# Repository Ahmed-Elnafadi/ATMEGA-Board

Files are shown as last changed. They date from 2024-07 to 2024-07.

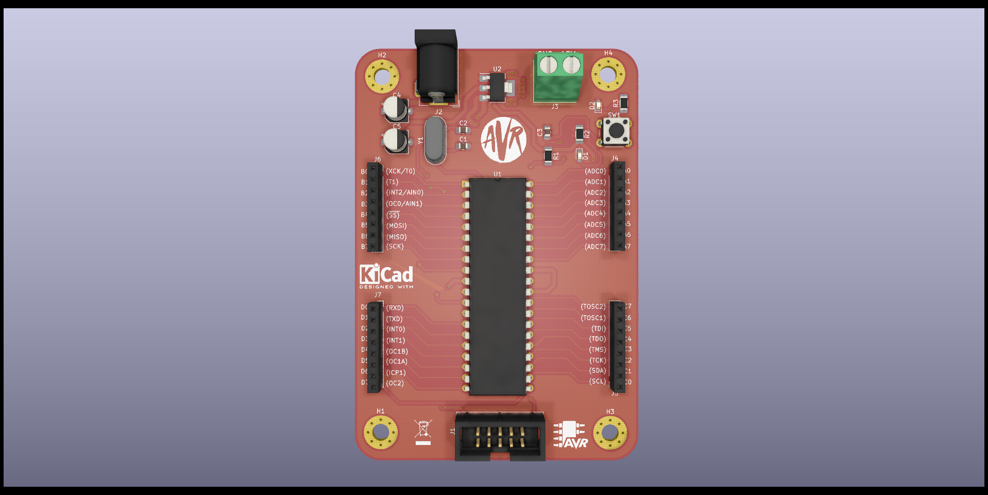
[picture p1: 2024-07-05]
ATMEGA32A_PU_V1_1.png

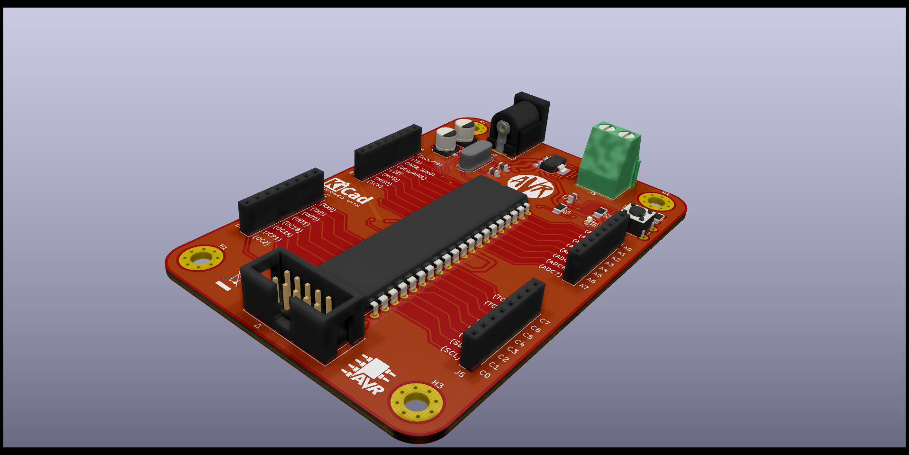
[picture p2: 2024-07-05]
ATMEGA32A_PU_V1_2.png

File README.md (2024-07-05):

# ATMEGA-Board
Developed ATMEGA board for Embedded System Engineers using KiCad Software. 
ATMEGA32A_PU_V1_1

# Real Product after Manufacturing and Assembling:
Real Board

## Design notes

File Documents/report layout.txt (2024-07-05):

Info: Checking netlist symbol footprint "J2:/620A4396:Connector_BarrelJack:BarrelJack_Wuerth_6941xx301002".
Info: Checking netlist symbol footprint "Y1:/620AA581:Crystal:Crystal_HC49-4H_Vertical".
Info: Checking netlist symbol footprint "U2:/620A79AD:Package_TO_SOT_SMD:TO-252-3_TabPin2".
Info: Checking netlist symbol footprint "U1:/62091506:Package_DIP:DIP-40_W15.24mm".
Info: Checking netlist symbol footprint "SW1:/620B355E:Button_Switch_THT:SW_PUSH_6mm".
Info: Checking netlist symbol footprint "R2:/620D214D:Resistor_SMD:R_1206_3216Metric_Pad1.30x1.75mm_HandSolder".
Info: Checking netlist symbol footprint "R1:/620B46D2:Resistor_SMD:R_1206_3216Metric_Pad1.30x1.75mm_HandSolder".
Info: Checking netlist symbol footprint "J7:/620DFF1D:Connector_PinSocket_2.54mm:PinSocket_1x08_P2.54mm_Vertical".
Info: Checking netlist symbol footprint "J6:/620DE13E:Connector_PinSocket_2.54mm:PinSocket_1x08_P2.54mm_Vertical".
Info: Checking netlist symbol footprint "J5:/620E2409:Connector_PinSocket_2.54mm:PinSocket_1x08_P2.54mm_Vertical".
Info: Checking netlist symbol footprint "J4:/620E0EA3:Connector_PinSocket_2.54mm:PinSocket_1x08_P2.54mm_Vertical".
Info: Checking netlist symbol footprint "J3:/620A65EF:TerminalBlock_Phoenix:TerminalBlock_Phoenix_MKDS-1,5-2_1x02_P5.00mm_Horizontal".
Info: Checking netlist symbol footprint "C1:/620AC6F6:Capacitor_SMD:C_0805_2012Metric_Pad1.18x1.45mm_HandSolder".
Info: Checking netlist symbol footprint "J1:/620DBA1B:Connector_IDC:IDC-Header_2x05_P2.54mm_Vertical".
Info: Checking netlist symbol footprint "H4:/620AEA69:MountingHole:MountingHole_4mm_Pad_Via".
Info: Checking netlist symbol footprint "H3:/620B0146:MountingHole:MountingHole_4mm_Pad_Via".
Info: Checking netlist symbol footprint "H2:/620AF71E:MountingHole:MountingHole_4mm_Pad_Via".
Info: Checking netlist symbol footprint "H1:/620AFCA4:MountingHole:MountingHole_4mm_Pad_Via".
Info: Checking netlist symbol footprint "D1:/620D2A8D:LED_SMD:LED_0603_1608Metric_Pad1.05x0.95mm_HandSolder".
Info: Checking netlist symbol footprint "C5:/620C8B24:Capacitor_SMD:CP_Elec_5x5.3".
Info: Checking netlist symbol footprint "C4:/620C6410:Capacitor_SMD:CP_Elec_5x5.3".
Info: Checking netlist symbol footprint "C3:/620B60D1:Capacitor_SMD:C_0805_2012Metric_Pad1.18x1.45mm_HandSolder".
Info: Checking netlist symbol footprint "C2:/620ACF85:Capacitor_SMD:C_0805_2012Metric_Pad1.18x1.45mm_HandSolder".

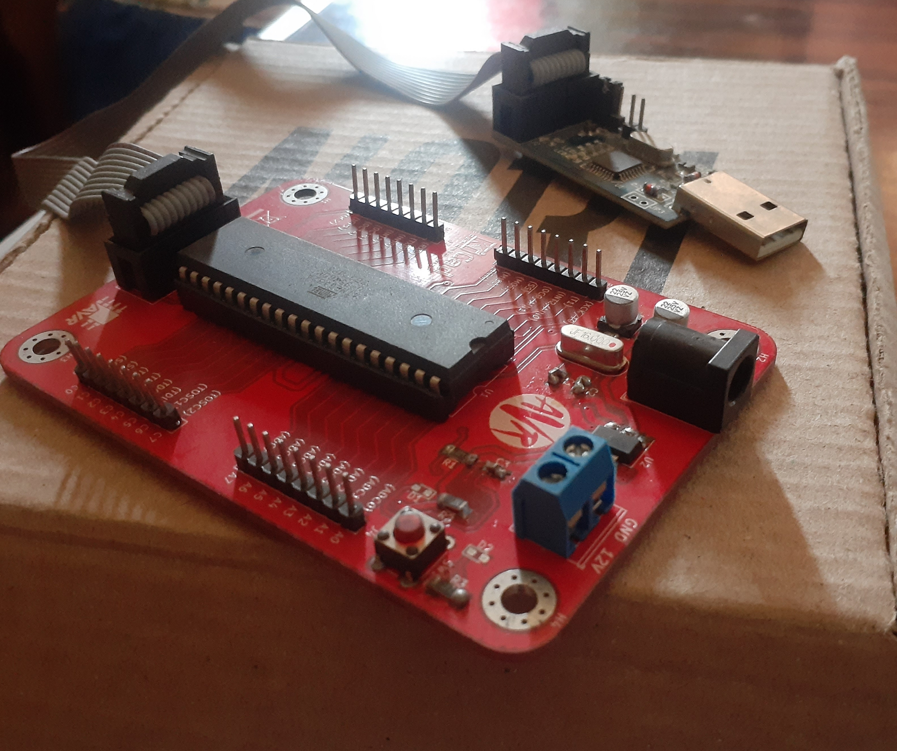
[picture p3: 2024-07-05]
Real Board.jpg

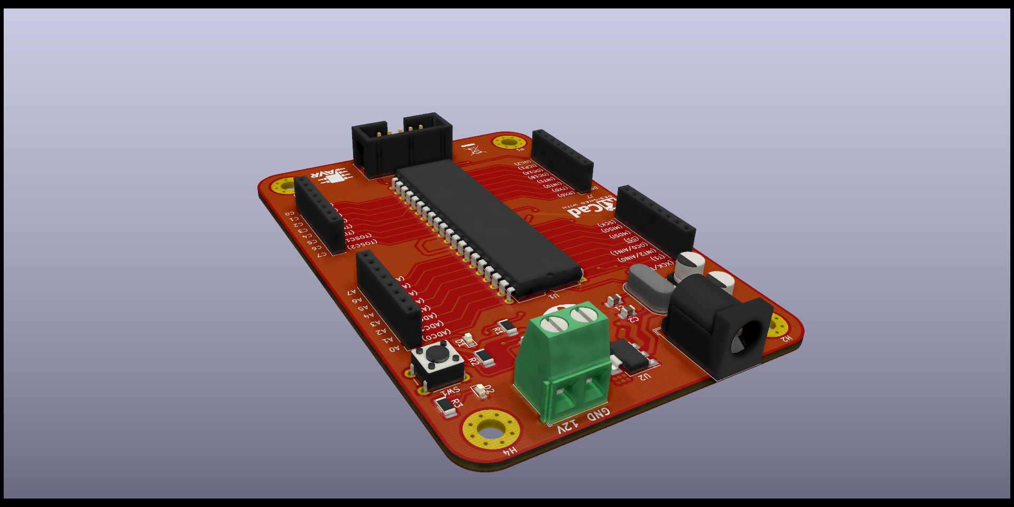
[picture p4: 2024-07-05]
ATMEGA32A_PU_V1_3.png

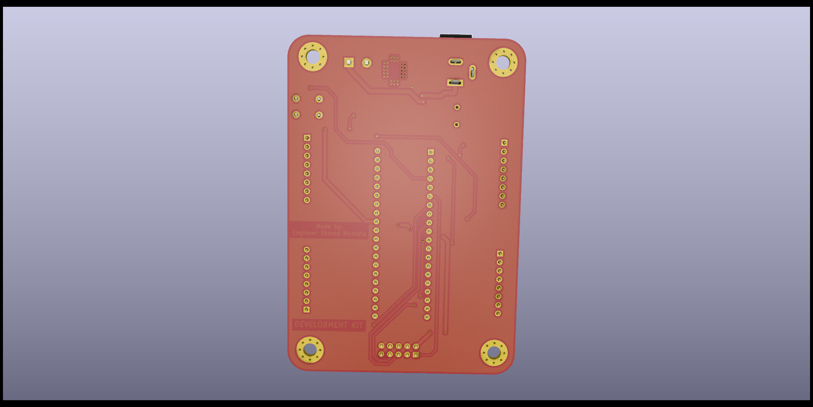
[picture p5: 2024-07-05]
ATMEGA32A_PU_V1_6.png

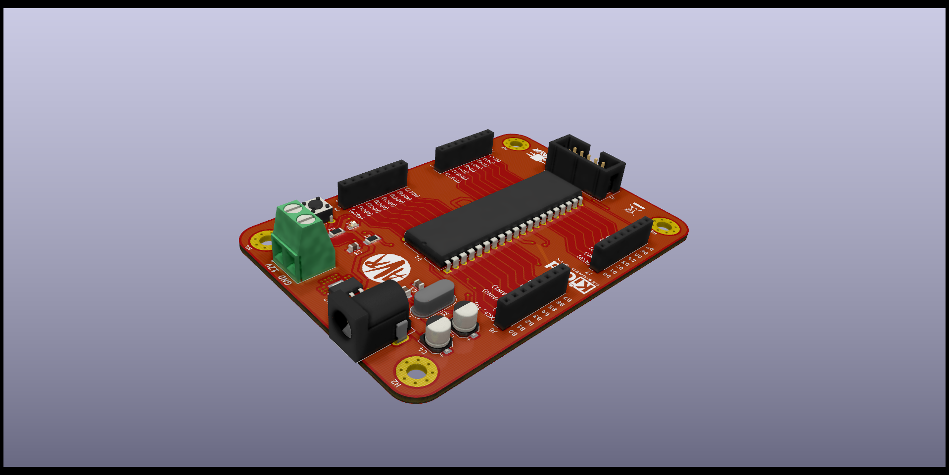
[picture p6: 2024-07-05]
ATMEGA32A_PU_V1_4.png

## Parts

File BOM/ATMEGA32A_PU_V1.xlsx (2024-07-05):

Id | Designator | Name of component | Package | Designation | Quantity | Price | Total Price | Supplier and ref
1 | J2 | DC power connector 2.1mm | Barrel Jack_Wuerth_6941xx301002 | Barrel_Jack_Switch | 1 | 1 | 1 | free electronics
2 | C1,C2 |  | C_0805_2012Metric_Pad1.18x1.45mm_Hand Solder | 22pf | 2 |  | 0
3 | C3 |  | C_0805_2012Metric_Pad1.18x1.45mm_Hand Solder | 100nf | 1 |  | 0
4 | C4,C5 |  | CP_Elec_5x5.3 | 10uf-25v | 2 |  | 0
5 | D1 | Led 0603 SMD | LED_0603_1608Metric_Pad1.05x0.95mm_Hand Solder | Red | 1 | 1 | 1 | free electronics
6 | J1 |  | IDC-Header_2x05_P2.54mm_Vertical | AVR-ISP-10 | 1 |  | 0
7 | J3 | 2pin PCB mount screw 5mm Pitch | Terminal Block_Phoenix_MKDS-1,5-2_1x02_P5.00mm_Horizontal | Screw_Terminal_01x02 | 1 | 1.75 | 1.75 | RAM
8 | J4,J5,J6,J7 | Pin Header 2.54 1x8 Female | Pin Socket_1x08_P2.54mm_Vertical | Conn_01x08_Female | 4 | 2.5 | 10 | RAM
9 | R1,R2,R3 | SMD resistor 1206 | R_1206_3216Metric_Pad1.30x1.75mm_Hand Solder | 220 | 3 | 5 | 15 | RAM
10 | SW1 | Press 4pin 6x6 | SW_PUSH_6mm | SW_Push | 1 | 0.5 | 0.5 | free electronics
11 | U1 | ATmega32A-PU | DIP-40_W15.24mm | ATmega32A-PU | 1 | 95 | 95 | free electronics
12 | Y1 | THH Crystal Oscillator | Crystal_HC49-4H_Vertical | 16MHz | 1 | 3 | 3 | RAM
13 | U2 | SMD Regulator 5v | SOT-223-3_TabPin2 | AMS1117-5.0 | 1 | 5 | 5 | RAM
14 | D2 | Led 0603 SMD | LED_0603_1608Metric_Pad1.05x0.95mm_Hand Solder | BLUE | 1 | 1 | 1 | free electronics
 |  |  |  |  | SUM | 115.75 | 133.25

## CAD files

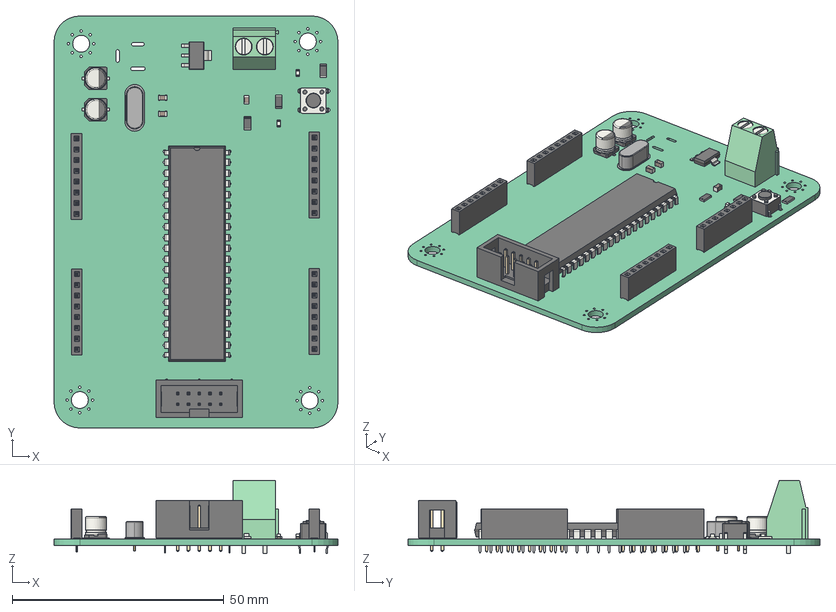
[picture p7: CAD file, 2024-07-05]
Step File/Atmega32.step
67.1 x 97.3 x 17.3 mm
Local_CS_ca74
Pcb_ca74
C1_C_0805_2012Metric_6209AD0E x 3
C4_CP_Elec_5x53_6209AD58 x 2
D1_LED_0603_1608Metric_6209D028 x 2
J1_IDC_Header_2x05_P254mm_Vertical_6209AE02
J3_TerminalBlock_Phoenix_MKDS_15_2_1x02_P500mm_Horizontal_6209AE4B
J4_PinSocket_1x08_P254mm_Vertical_6209AE67 x 4
R1_R_1206_3216Metric_6209C590 x 3
SW1_SW_PUSH_6mm_6209C4E6
U1_DIP-40_W15.24mm_6209AF38
Y1_Crystal_HC49-4H_Vertical_6209AF77
U2_SOT_223_6209B22F

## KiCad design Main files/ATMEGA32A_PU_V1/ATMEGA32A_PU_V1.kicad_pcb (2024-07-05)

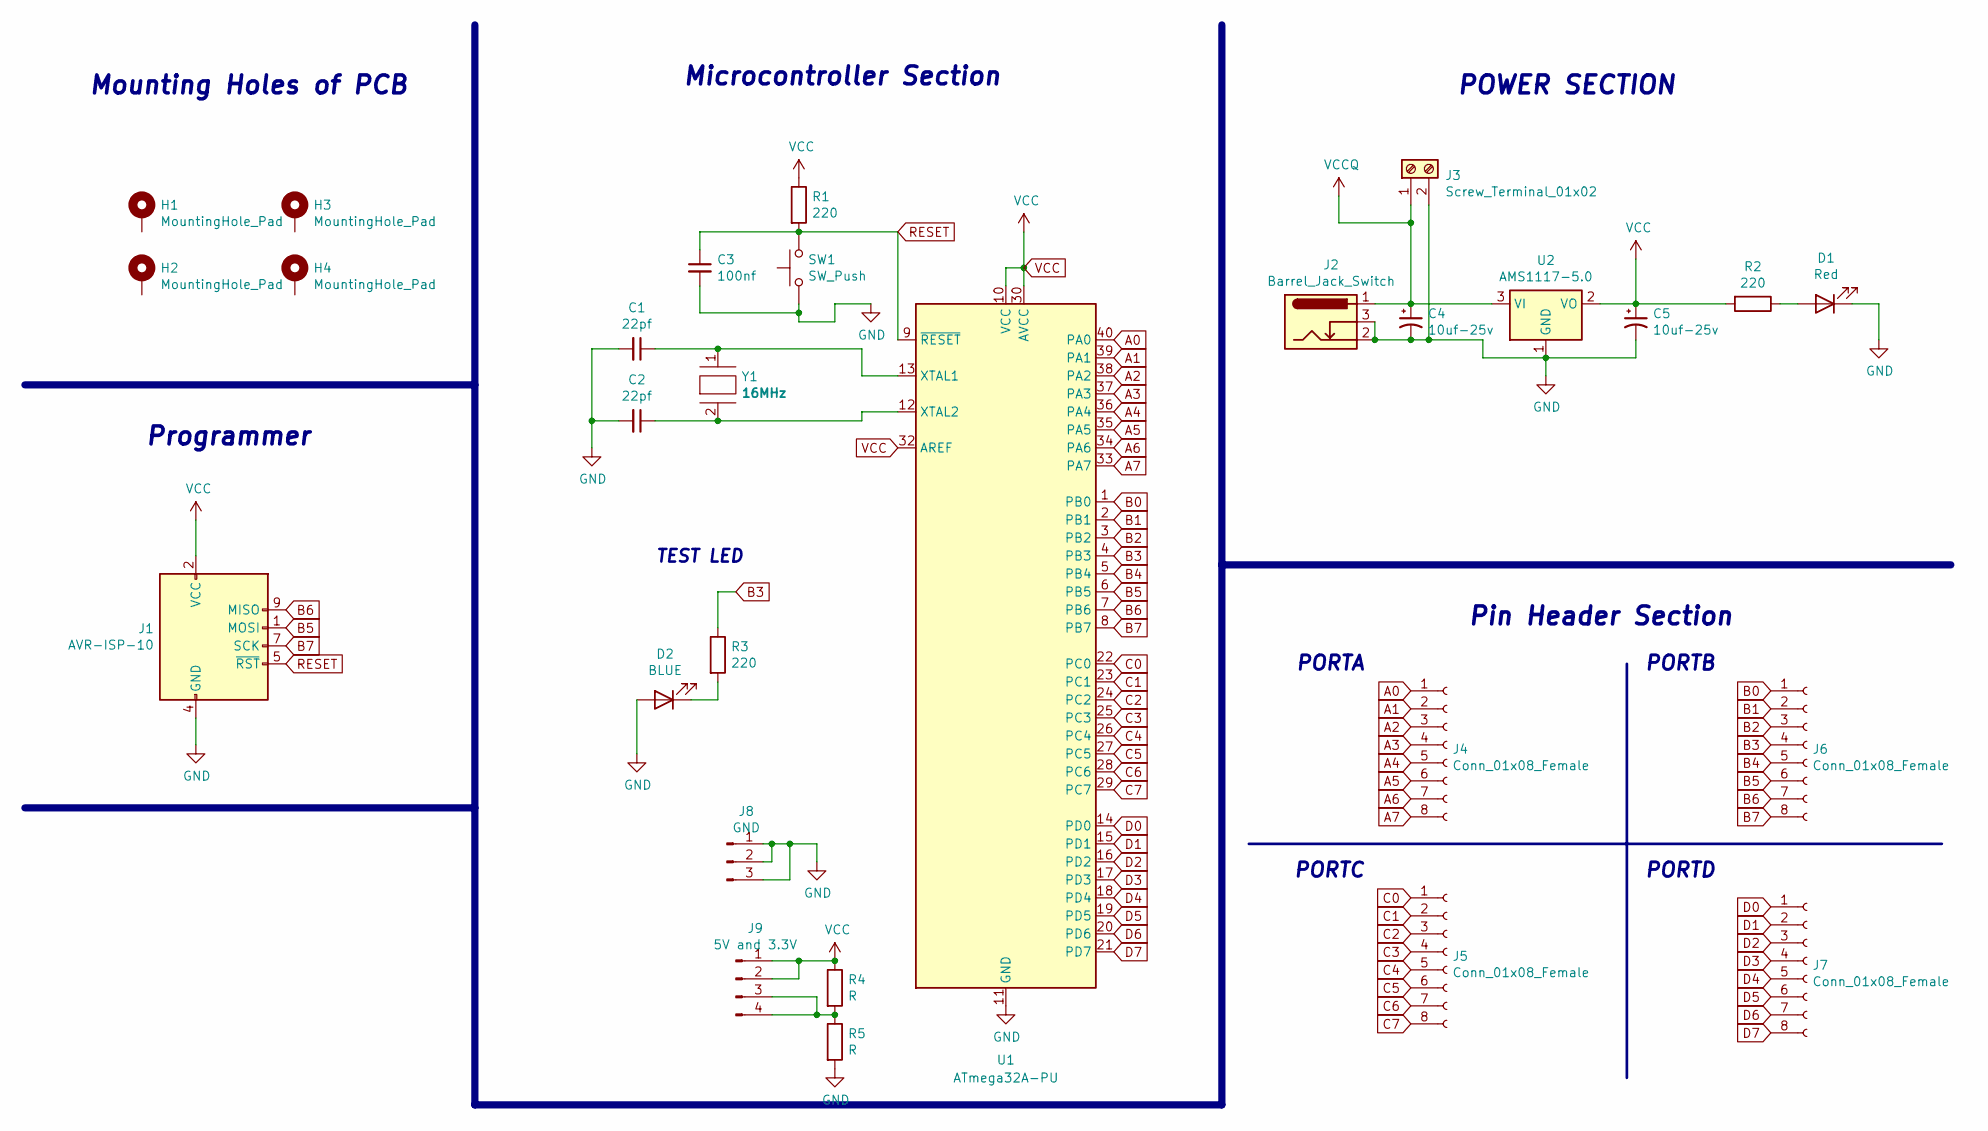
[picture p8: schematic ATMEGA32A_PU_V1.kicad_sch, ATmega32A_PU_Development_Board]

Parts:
C1, C2: 22pf; C_0805_2012Metric_Pad1.18x1.45mm_HandSolder
C3: 100nf; C_0805_2012Metric_Pad1.18x1.45mm_HandSolder
C4, C5: 10uf-25v; CP_Elec_5x5.3
D1: Red; LED_0603_1608Metric_Pad1.05x0.95mm_HandSolder
D2: BLUE; LED_0603_1608Metric_Pad1.05x0.95mm_HandSolder
H1, H2, H3, H4: MountingHole_Pad; MountingHole_4mm_Pad_Via
J1: AVR-ISP-10; IDC-Header_2x05_P2.54mm_Vertical
J2: Barrel_Jack_Switch; BarrelJack_Wuerth_6941xx301002
J3: Screw_Terminal_01x02; TerminalBlock_Phoenix_MKDS-1,5-2_1x02_P5.00mm_Horizontal
J4, J5, J6, J7: Conn_01x08_Female; PinHeader_1x08_P2.54mm_Vertical
J8: GND; PinHeader_1x03_P2.54mm_Vertical
J9: 5V and 3.3V; PinHeader_1x04_P2.54mm_Vertical
R1, R2, R3: 220; R_1206_3216Metric_Pad1.30x1.75mm_HandSolder
R4, R5: R; R_1206_3216Metric_Pad1.30x1.75mm_HandSolder
SW1: SW_Push; SW_PUSH_6mm
U1: ATmega32A-PU; DIP-40_W15.24mm
U2: AMS1117-5.0; SOT-223-3_TabPin2
Y1: 16MHz; Crystal_HC49-4H_Vertical

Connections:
A0: J4.1, U1.40 (PA0)
A1: J4.2, U1.39 (PA1)
A2: J4.3, U1.38 (PA2)
A3: J4.4, U1.37 (PA3)
A4: J4.5, U1.36 (PA4)
A5: J4.6, U1.35 (PA5)
A6: J4.7, U1.34 (PA6)
A7: J4.8, U1.33 (PA7)
B0: J6.1, U1.1 (PB0)
B1: J6.2, U1.2 (PB1)
B2: J6.3, U1.3 (PB2)
B3: J6.4, R3.1, U1.4 (PB3)
B4: J6.5, U1.5 (PB4)
B5: J1.1 (MOSI), J6.6, U1.6 (PB5)
B6: J1.9 (MISO), J6.7, U1.7 (PB6)
B7: J1.7 (SCK), J6.8, U1.8 (PB7)
C0: J5.1, U1.22 (PC0)
C1: J5.2, U1.23 (PC1)
C2: J5.3, U1.24 (PC2)
C3: J5.4, U1.25 (PC3)
C4: J5.5, U1.26 (PC4)
C5: J5.6, U1.27 (PC5)
C6: J5.7, U1.28 (PC6)
C7: J5.8, U1.29 (PC7)
D0: J7.1, U1.14 (PD0)
D1: J7.2, U1.15 (PD1)
D2: J7.3, U1.16 (PD2)
D3: J7.4, U1.17 (PD3)
D4: J7.5, U1.18 (PD4)
D5: J7.6, U1.19 (PD5)
D6: J7.7, U1.20 (PD6)
D7: J7.8, U1.21 (PD7)
GND: C1.2, C2.2, C3.2, C4.2, C5.2, D1.1 (K), D2.2 (A), J1.4 (GND), J1.6 (GND), J1.8 (GND), J1.10 (GND), J2.2, J2.3, J3.2, J8.1, J8.2, J8.3, R5.2, SW1.1, U1.11 (GND), U1.31 (GND), U2.1 (GND)
unnamed: C1.1, U1.13 (XTAL1), Y1.1
unnamed: C2.1, U1.12 (XTAL2), Y1.2
unnamed: D1.2 (A), R2.1
unnamed: D2.1 (K), R3.2
unnamed: J9.3, J9.4, R4.2, R5.1
RESET: C3.1, J1.5 (~RST), R1.2, SW1.2, U1.9 (~RESET)
VCC: C5.1, J1.2 (VCC), J9.1, J9.2, R1.1, R2.2, R4.1, U1.10 (VCC), U1.30 (AVCC), U1.32 (AREF), U2.2 (VO)
VCCQ: C4.1, J2.1, J3.1, U2.3 (VI)

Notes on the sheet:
PORTA
PORTB
PORTC
TEST LED
Pin Header Section
Microcontroller Section
Mounting Holes of PCB
Programmer
PORTD
POWER SECTION

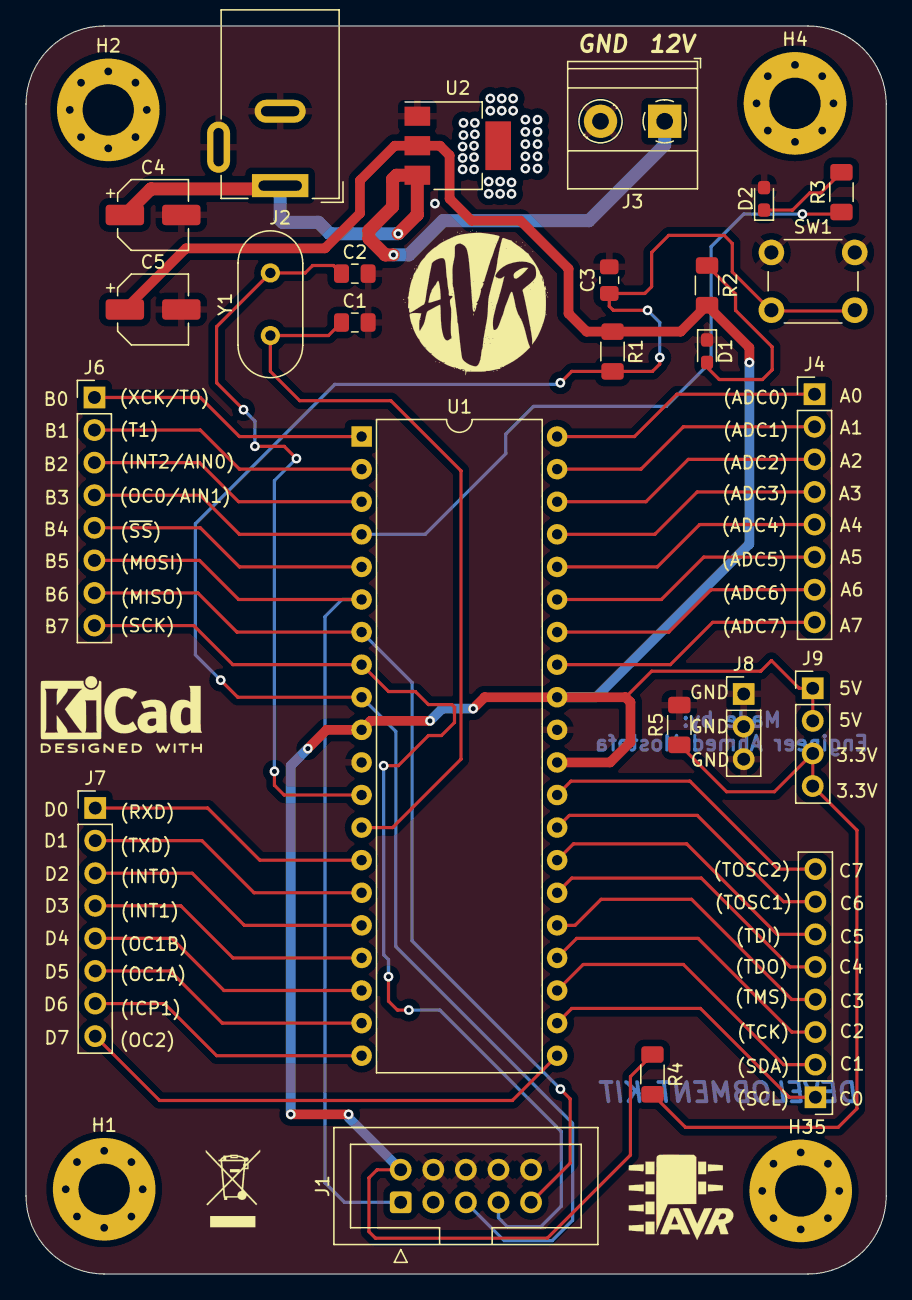
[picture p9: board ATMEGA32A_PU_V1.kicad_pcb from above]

Board: 2 copper layers, 67.1 x 97.3 mm, 29 parts (0 on the bottom side), 41 nets.
